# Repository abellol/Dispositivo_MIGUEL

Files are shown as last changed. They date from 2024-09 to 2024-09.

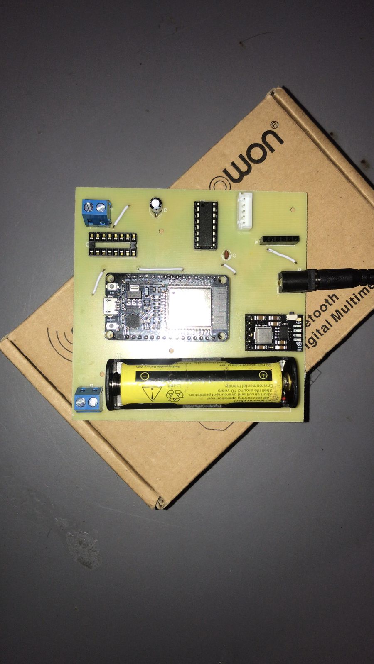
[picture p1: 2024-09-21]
Evidencias/pcb_componentes_2.jpg

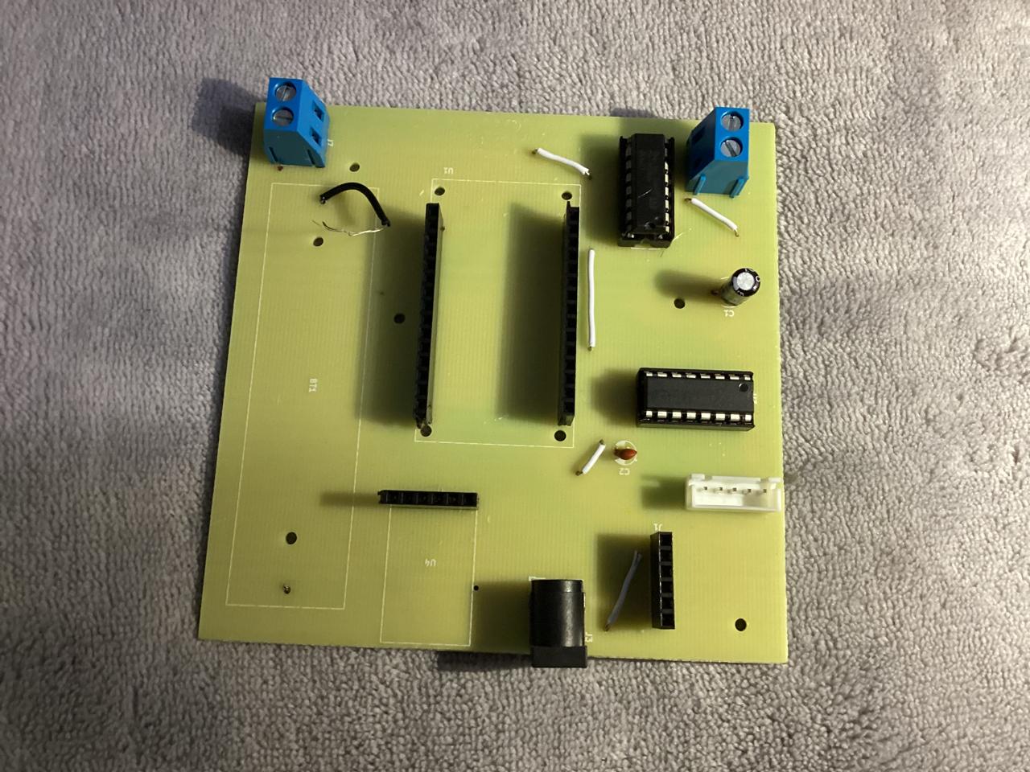
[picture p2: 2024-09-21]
Evidencias/pcb_componentes.jpg

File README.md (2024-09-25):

# Dispositivo_MIGUEL
Desarrollo e implementación de Robot con tecnología LiDAR
### Integrantes
El proyecto fue diseñado y desarrollado por:
| Nombre | Programa |
|:-|:-|
|Alejandro Bello León | ``Ing. Mecatrónica``|
|Ricardo Taizoo Avila Molina | ``Ing. Mecatrónica``|
|Fabio Guillermo Castellanos Lenes | ``Física``|

## Introducción
MIGUEL (Mapeo Inteligente Graficador Utilizando Escaner LiDAR) es un dispositivo autónomo diseñado para navegar por entornos controlados evitando obstaculos y tomando decisiones en tiempo real basadas en los datos que recibe. El vehículo escanea y grafica continuamente su entorno, identificando obstáculos para asegurar un movimiento eficiente dentro del espacio.

El proyecto es una propuesta que abre paso a la exploración a profuncidad de temas relacionados con la robótica, automatización y la integración de sensores.

Puedes visitar nuestra [wiki del proyecto](https://github.com/abellol/Dispositivo_MIGUEL/wiki).

## Póster

(https://postimg.cc/tYdmCQzM)

## Resultado final

https://github.com/user-attachments/assets/6533ad30-b109-4fec-b7e1-59a3a72a6980

## Vídeo explicativo del proyecto

Pueden ver el video en este [enlace](https://www.youtube.com/watch?v=PxDm3hlaaLA) a YouTube

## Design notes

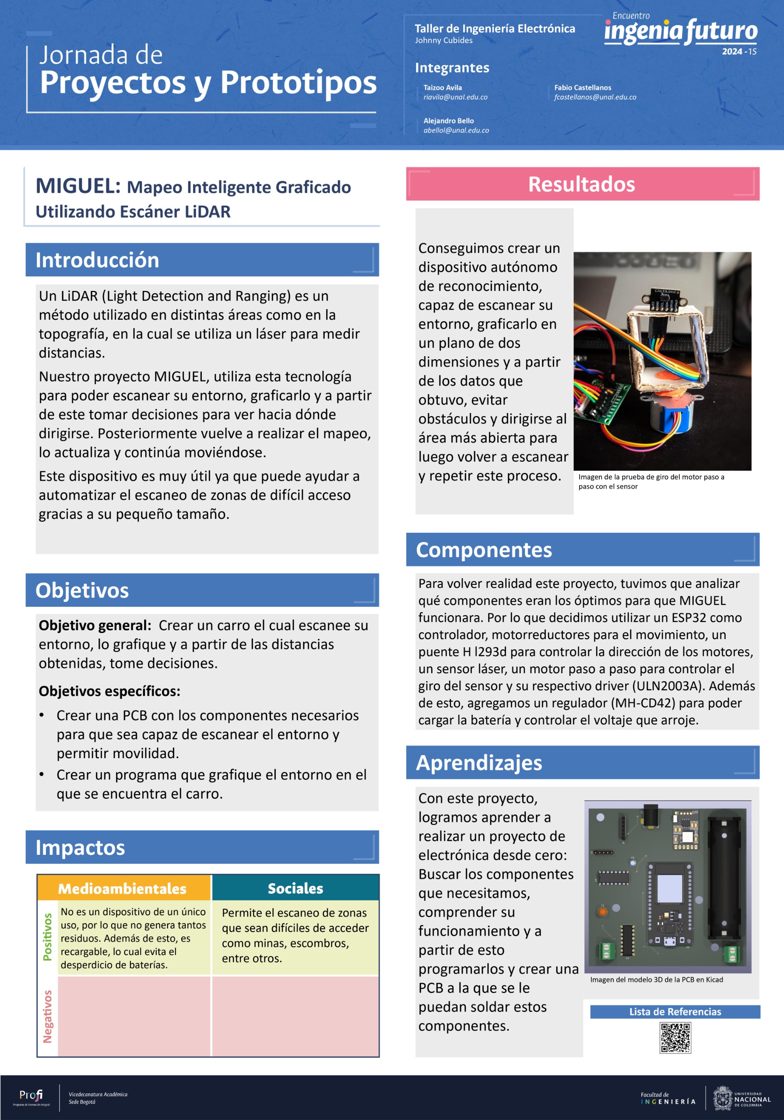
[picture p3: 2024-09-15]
Evidencias/poster_ingenia.jpg

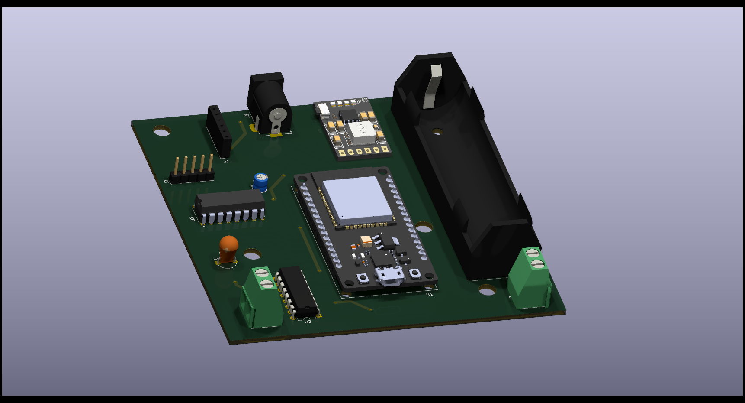
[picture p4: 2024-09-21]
Evidencias/vista_3_MIGUEL.png

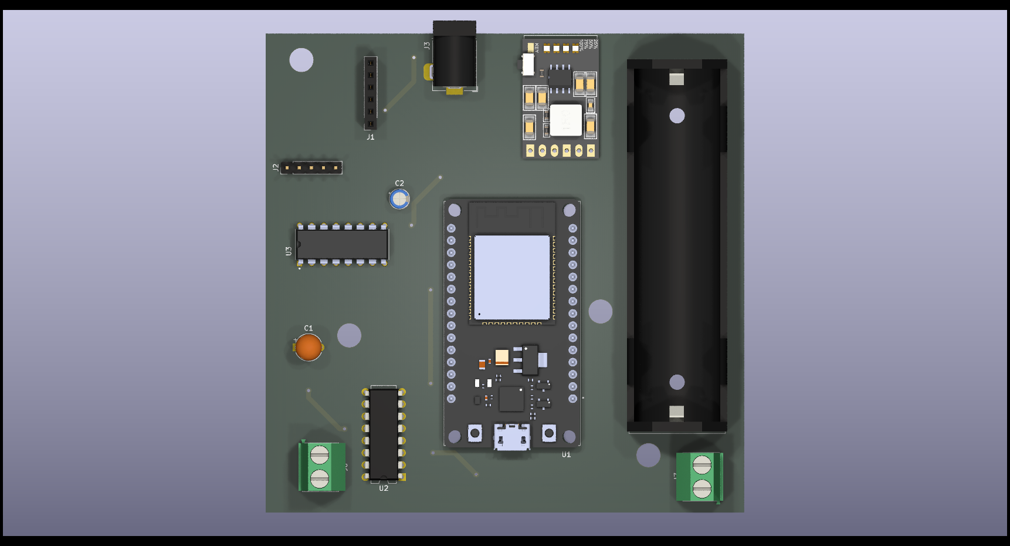
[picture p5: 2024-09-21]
Evidencias/vista_2_MIGUEL.png

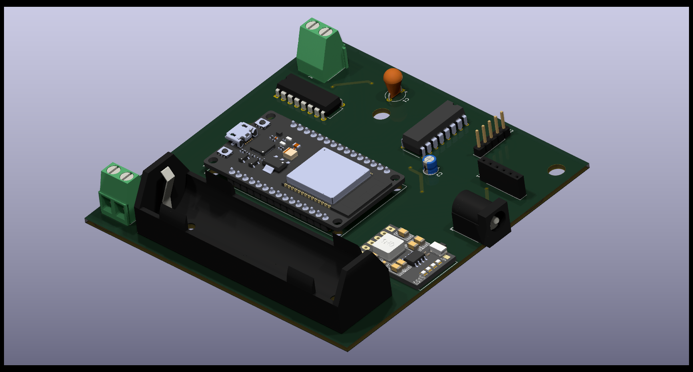
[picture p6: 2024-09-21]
Evidencias/vista_4_MIGUEL.png

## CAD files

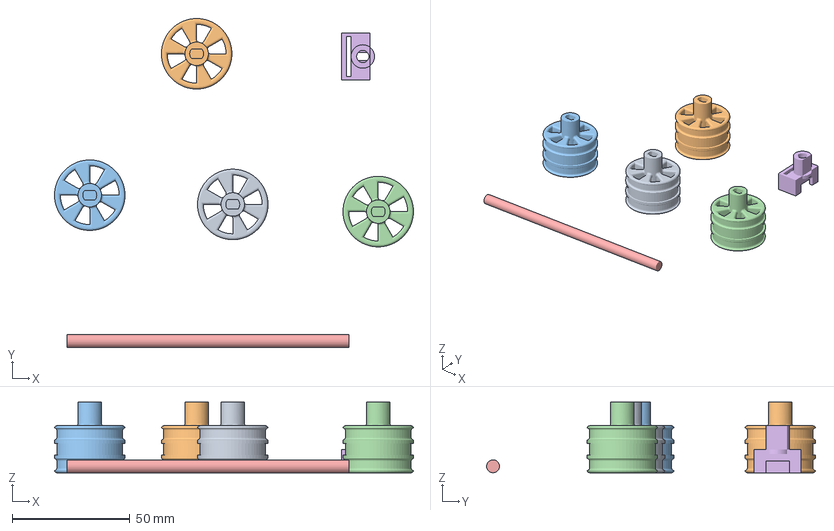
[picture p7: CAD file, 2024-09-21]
Case/piezas_pequeñas.3mf
152.7 x 139.9 x 30.0 mm
Rines.stl x 4
Eje.stl
Soporte sensor.stl

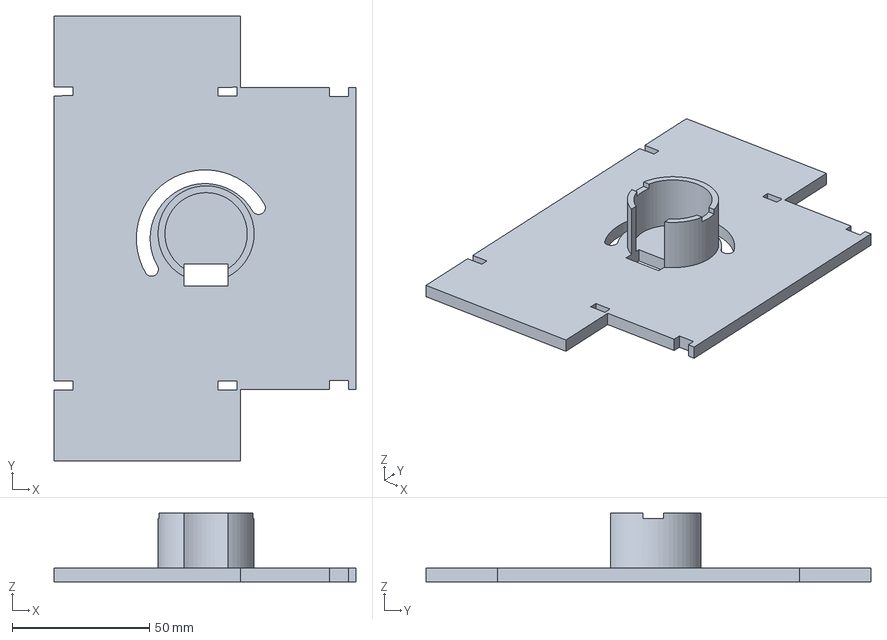
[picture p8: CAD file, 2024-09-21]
Case/tapa_carcasa_real.3mf
110.0 x 162.0 x 25.0 mm

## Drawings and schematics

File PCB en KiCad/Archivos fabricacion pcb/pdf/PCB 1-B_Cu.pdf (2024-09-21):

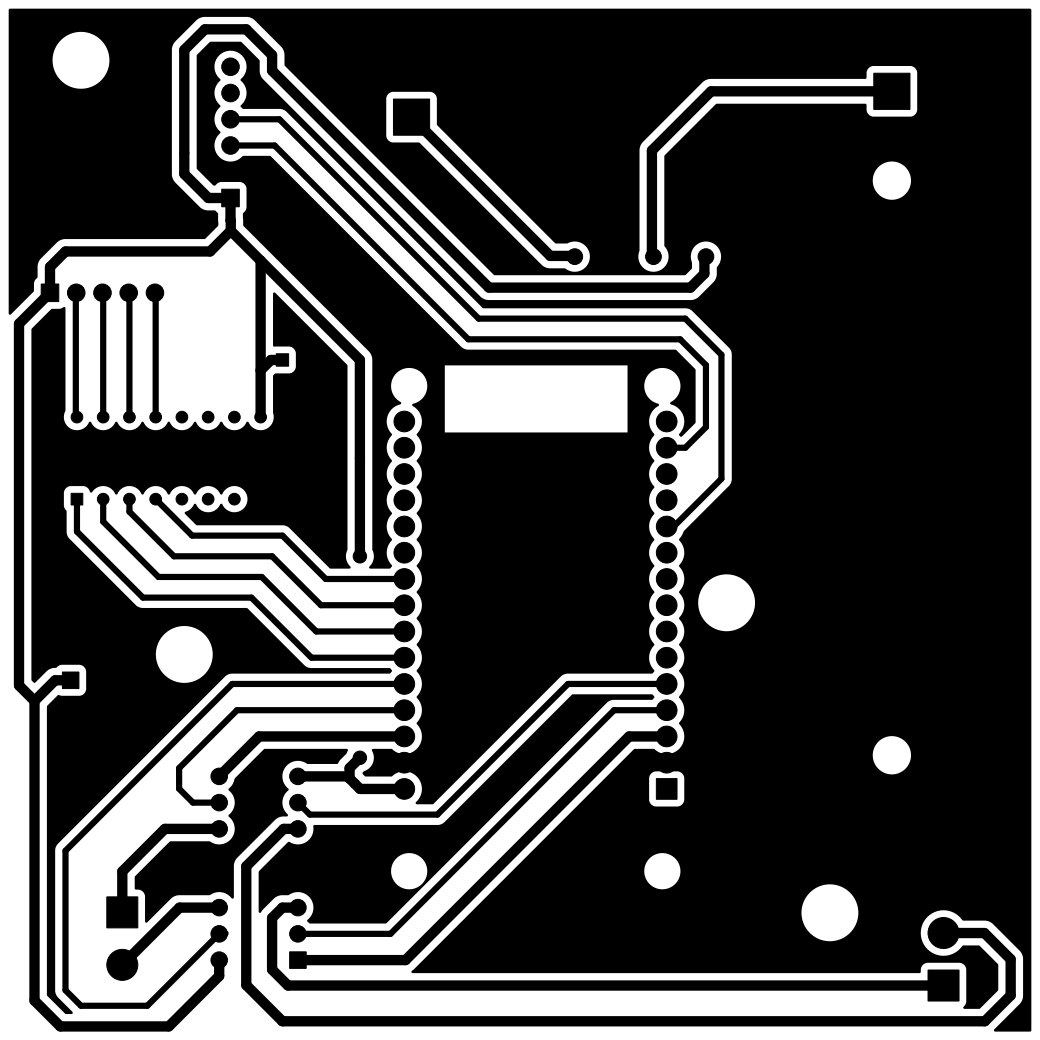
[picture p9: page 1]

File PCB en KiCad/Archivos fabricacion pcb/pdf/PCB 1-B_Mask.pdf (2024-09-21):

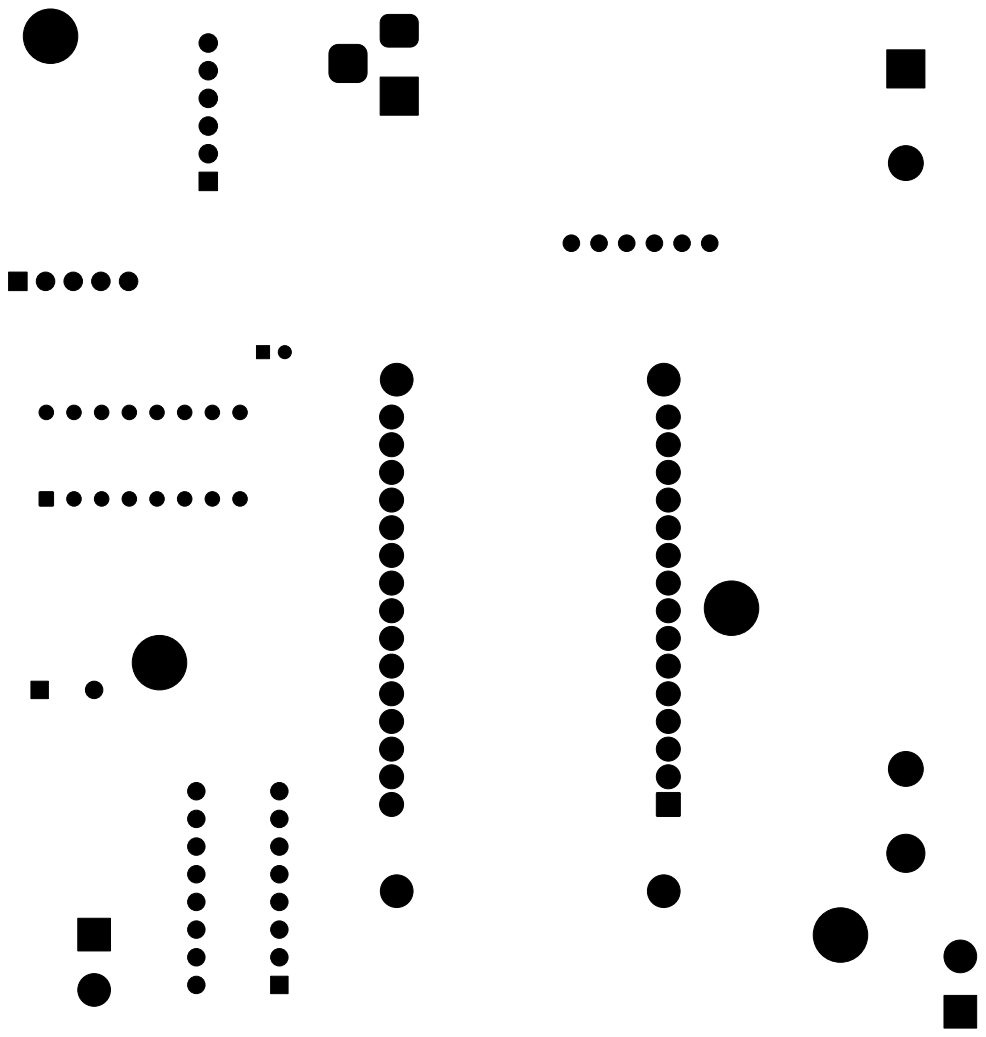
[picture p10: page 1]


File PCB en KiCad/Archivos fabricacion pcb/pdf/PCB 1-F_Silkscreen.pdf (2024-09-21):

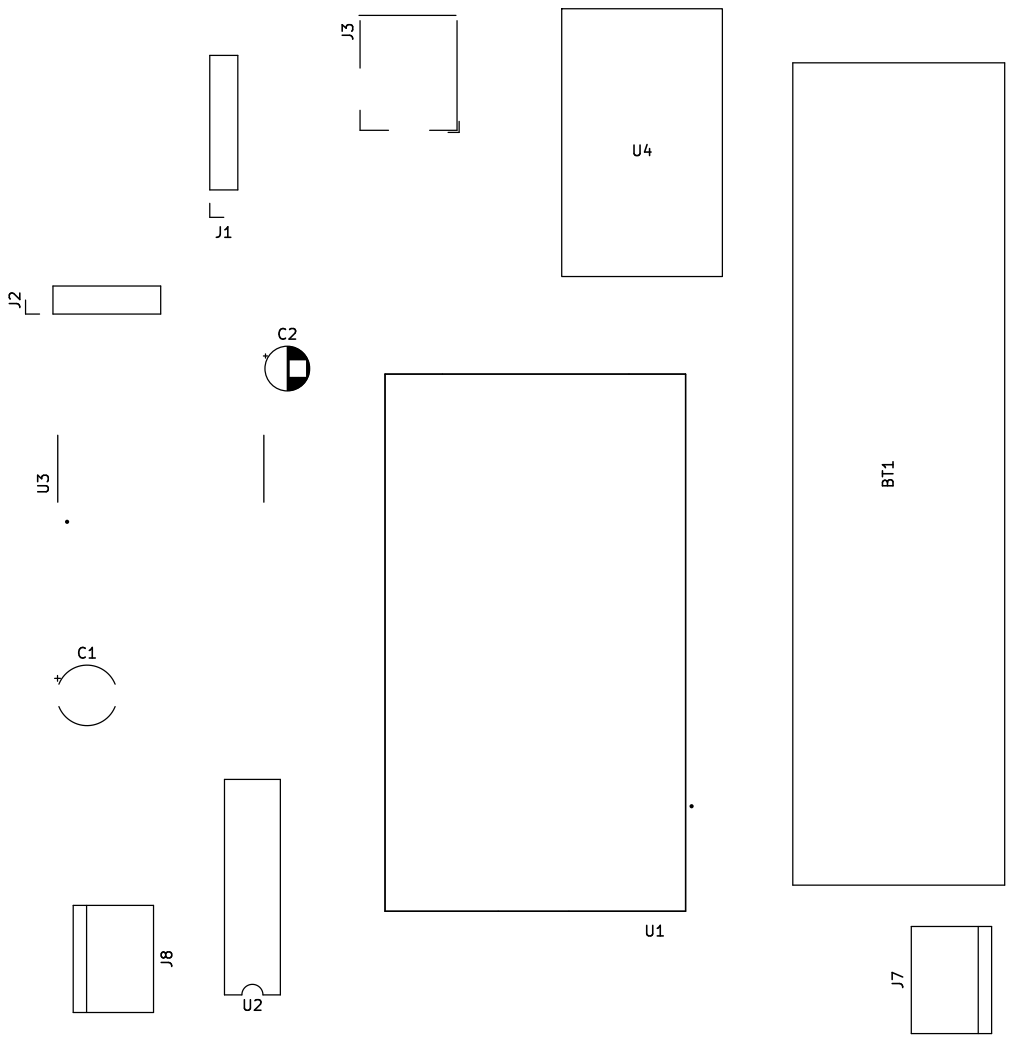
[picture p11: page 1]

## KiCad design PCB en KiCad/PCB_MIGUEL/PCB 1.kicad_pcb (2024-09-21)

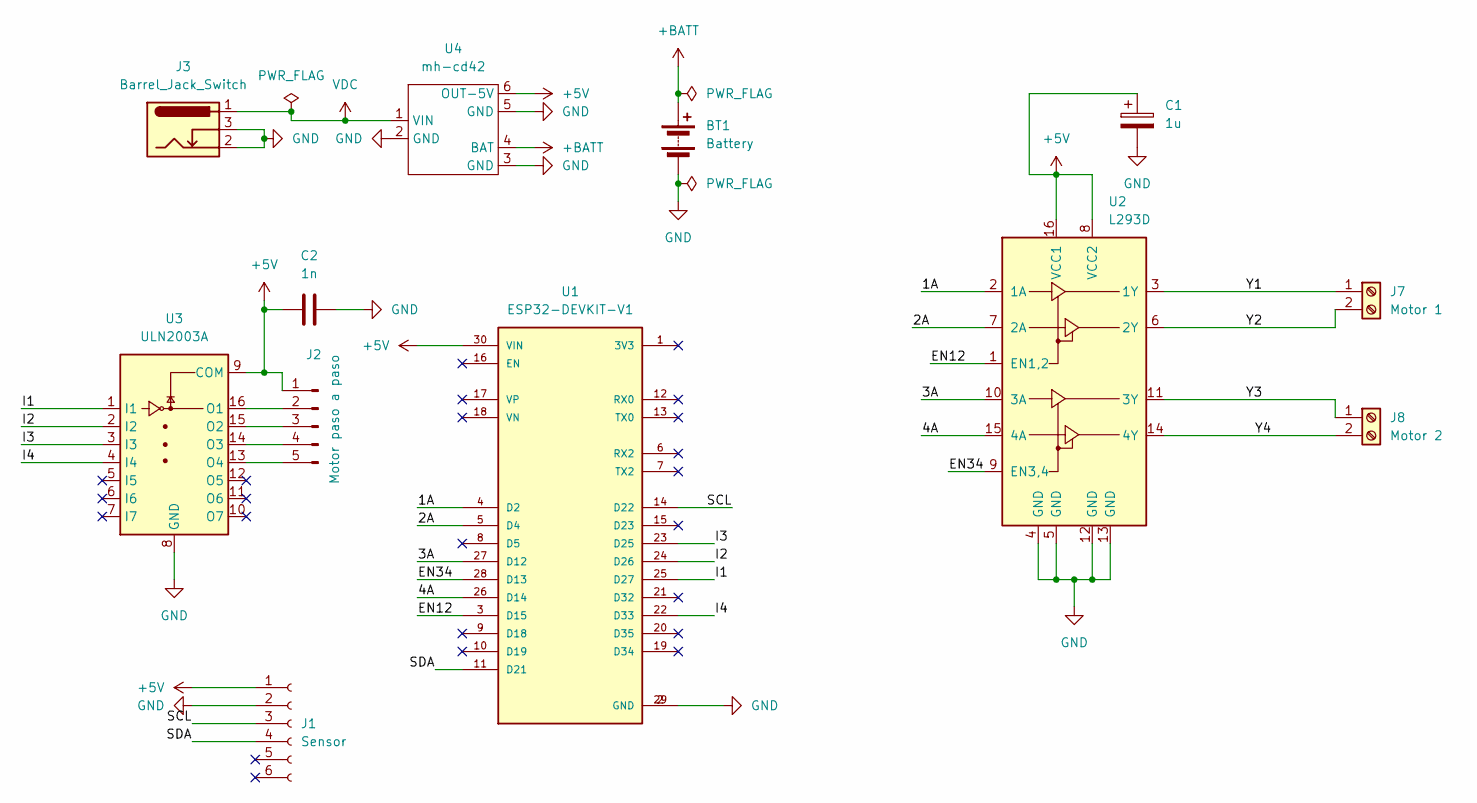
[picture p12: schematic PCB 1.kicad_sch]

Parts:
BT1: Battery; BatteryHolder_MPD_BH-18650-PC2
C1: 1u; CP_Radial_Tantal_D5.5mm_P5.00mm
C2: 1n; CP_Radial_D4.0mm_P2.00mm
J1: Sensor; PinSocket_1x06_P2.54mm_Vertical
J2: Motor paso a paso; PinHeader_1x05_P2.54mm_Vertical
J3: Barrel_Jack_Switch; BarrelJack_Horizontal
J7: Motor 1; TerminalBlock_bornier-2_P5.08mm
J8: Motor 2; TerminalBlock_bornier-2_P5.08mm
U1: ESP32-DEVKIT-V1; MODULE_ESP32_DEVKIT_V1; PARTREV N/A
U2: L293D; DIP-16_W7.62mm
U3: ULN2003A; DIP794W45P254L1969H508Q16
U4: mh-cd42

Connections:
+5V: C1.1, C2.1, J1.1, J2.1, U1.30 (VIN), U2.8 (VCC2), U2.16 (VCC1), U3.9 (COM), U4.6 (OUT-5V)
+BATT: BT1.1 (+), U4.4 (BAT)
/1A: U1.4 (D2), U2.2 (1A)
/2A: U1.5 (D4), U2.7 (2A)
/3A: U1.27 (D12), U2.10 (3A)
/4A: U1.26 (D14), U2.15 (4A)
/EN12: U1.3 (D15), U2.1 (EN1,2)
/EN34: U1.28 (D13), U2.9 (EN3,4)
/I1: U1.25 (D27), U3.1 (I1)
/I2: U1.24 (D26), U3.2 (I2)
/I3: U1.23 (D25), U3.3 (I3)
/I4: U1.22 (D33), U3.4 (I4)
/SCL: J1.3, U1.14 (D22)
/SDA: J1.4, U1.11 (D21)
/Y1: J7.1, U2.3 (1Y)
/Y2: J7.2, U2.6 (2Y)
/Y3: J8.1, U2.11 (3Y)
/Y4: J8.2, U2.14 (4Y)
GND: BT1.2 (-), C1.2, C2.2, J1.2, J3.2, J3.3, U1.2 (GND), U1.29 (GND), U2.4 (GND), U2.5 (GND), U2.12 (GND), U2.13 (GND), U3.8 (GND), U4.2 (GND), U4.3 (GND), U4.5 (GND)
unnamed: J2.2, U3.16 (O1)
unnamed: J2.3, U3.15 (O2)
unnamed: J2.4, U3.14 (O3)
unnamed: J2.5, U3.13 (O4)
VDC: J3.1, U4.1 (VIN)

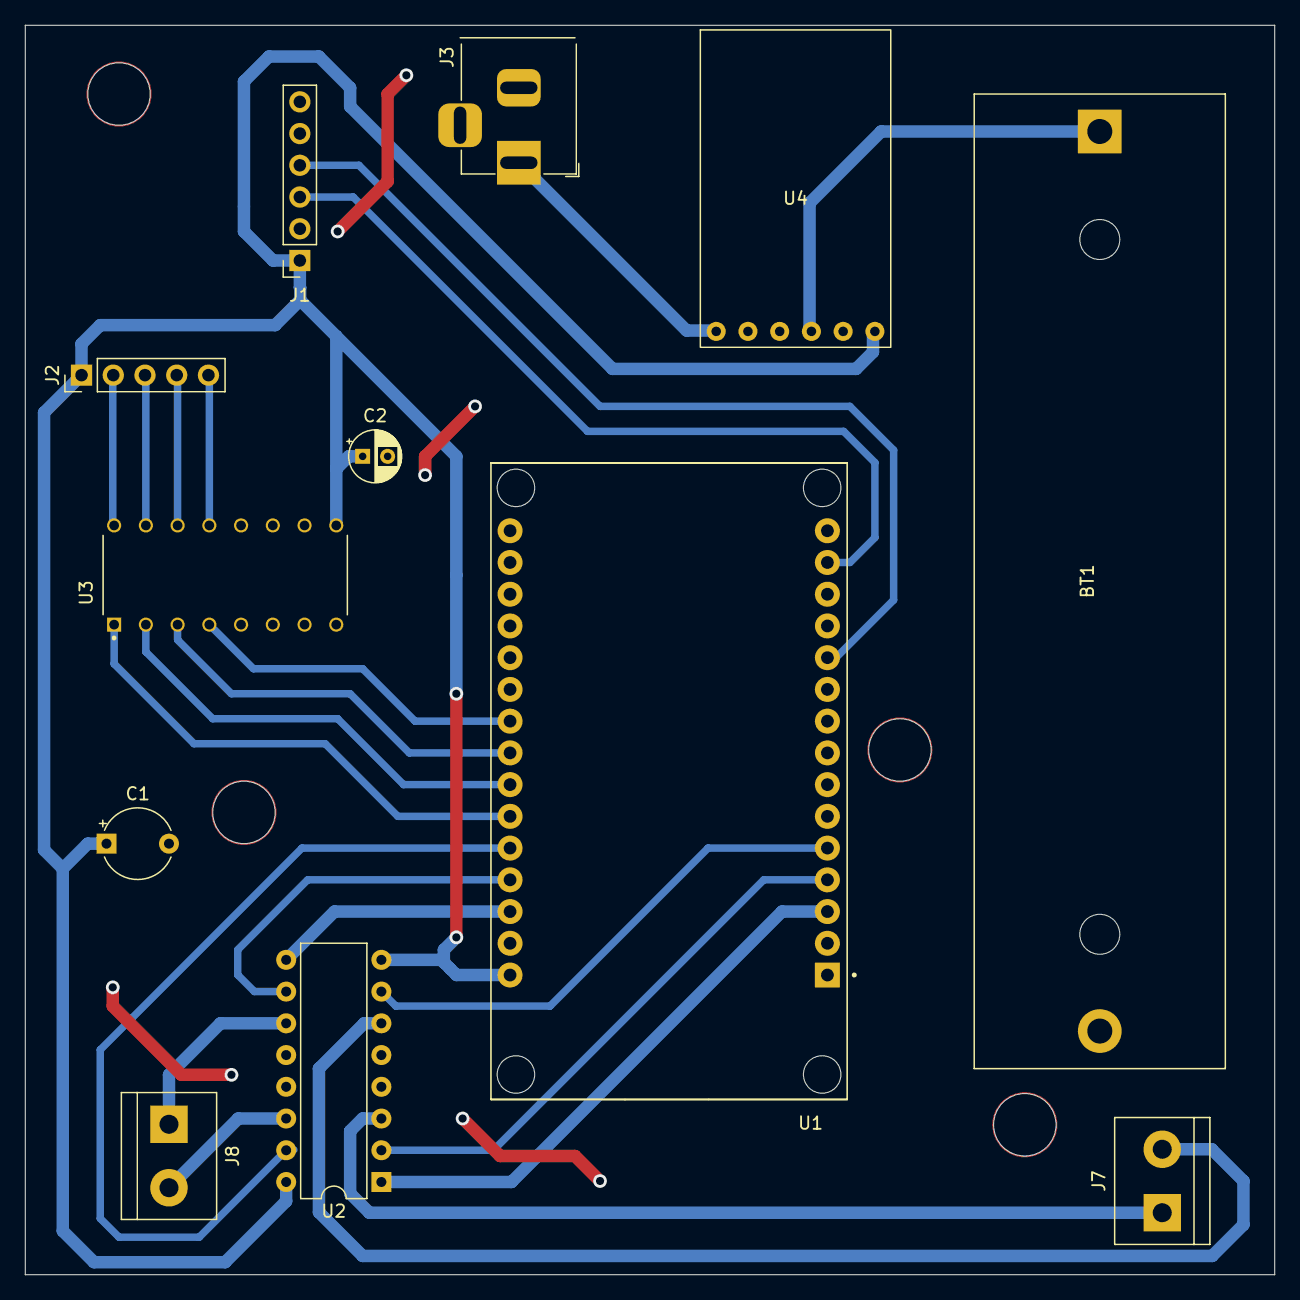
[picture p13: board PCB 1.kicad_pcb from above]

Board: 2 copper layers, 100.0 x 100.0 mm, 12 parts (0 on the bottom side), 24 nets.

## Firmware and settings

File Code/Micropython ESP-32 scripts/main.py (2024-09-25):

import socket
from machine import Pin, I2C
import time
import machine
from VL53L0X import VL53L0X
from wifiAP import connectSTA as connect

# Configuraciones de red
WIFI_SSID = "WIFI RITIN 2"
WIFI_PASSWORD = "Ritis2021"
SERVER_PORT = 3000
BUFFER_SIZE = 128
NUM_LECTURAS = 10

# Declarar los pines de los motorreductores
in1 = Pin(4, Pin.OUT)
in2 = Pin(2, Pin.OUT)
in3 = Pin(14, Pin.OUT)
in4 = Pin(12, Pin.OUT)
d13 = Pin(13, Pin.OUT)
d15 = Pin(15, Pin.OUT)

# Declarar pines del motor paso
IN1 = machine.Pin(27, machine.Pin.OUT)
IN2 = machine.Pin(26, machine.Pin.OUT)
IN3 = machine.Pin(25, machine.Pin.OUT)
IN4 = machine.Pin(33, machine.Pin.OUT)

# Función para controlar la polaridad de los motores frontales
def direction(dire:str):
    d13.value(1)
    d15.value(1)
    if dire == "forward":
        in1.value(1)
        in2.value(0)
        in3.value(1)
        in4.value(0)
    elif dire == "backward":
        in1.value(0)
        in2.value(1)
        in3.value(0)
        in4.value(1)
    elif dire == "left":
        in1.value(0)
        in2.value(1)
        in3.value(1)
        in4.value(0)
    elif dire == "right":
        in1.value(1)
        in2.value(0)
        in3.value(0)
        in4.value(1)
    elif dire == "stop":
        in1.value(0)
        in2.value(0)
        in3.value(0)
        in4.value(0)
# Función para mover el motor, con direccion a favor de las manecillas(1) y en contra(-1)
def motor_half_step(steps, delay, direction = 1):
  half_step = [
    [1, 0, 0, 0],
    [1, 1, 0, 0],
    [0, 1, 0, 0],
    [0, 1, 1, 0],
    [0, 0, 1, 0],
    [0, 0, 1, 1],
    [0, 0, 0, 1],
    [1, 0, 0, 1]
    ]
  if direction == 1:
    for combination in range(steps):
      for step in half_step:
          IN1.value(step[0])
          IN2.value(step[1])
          IN3.value(step[2])
          IN4.value(step[3])
          time.sleep_ms(delay)
  else:
    for combination in range(steps):
      
      for step in range(len(half_step)-1, -1, -1):
          IN1.value(half_step[step][0])
          IN2.value(half_step[step][1])
          IN3.value(half_step[step][2])
          IN4.value(half_step[step][3])
          time.sleep_ms(delay)
          
# Función para conectar el ESP32 a una red WiFi
def conectar_wifi(ssid, password):
    connect(ssid, password)
    print(f"Conectado a la red {ssid}")

# Función para inicializar el sensor VL53L0X
def inicializar_sensor_vl53l0x():
    i2c = I2C(0, scl=Pin(22), sda=Pin(21))
    sensor = VL53L0X(i2c)
    sensor.start()
    return sensor

# Función para crear un socket servidor
def crear_servidor(port):
    server_address = socket.getaddrinfo('0.0.0.0', port)[0][-1]
    sk = socket.socket()
    sk.setsockopt(socket.SOL_SOCKET, socket.SO_REUSEADDR, 1)  # Permitir reutilización del puerto
    sk.bind(server_address)
    sk.listen(1)
    print(f"Servidor escuchando en {server_address}")
    return sk

# Función para leer distancias del sensor y calcular un promedio
def leer_promedio_distancia(sensor, num_lecturas):
    distancia_total = 0
    for _ in range(num_lecturas):
        distancia = sensor.read() + 13  # Suma constante como calibración
        print(f'Distancia: {distancia} mm')
        distancia_total += distancia
        time.sleep(0.1)
    promedio = distancia_total / num_lecturas
    return promedio

# Función principal para manejar conexiones y enviar datos
def manejar_conexion(conn, sensor, num_lecturas, buffer_size):
    try:
        t = 0
        distancias = []
        for i in range(51):
            data = conn.recv(buffer_size)
            if not data:
                break 
            motor_half_step(10,1)
            print(f"Recibido: {data.decode()}")  # Mostrar el dato recibido
            
            # Leer el promedio de distancia y calcular el ángulo
            promedio_distancia = leer_promedio_distancia(sensor, num_lecturas)
            data_value = [promedio_distancia, t]
            t += (360 / 51)
            data_str = str(data_value)
            # Enviar el valor al cliente
            conn.sendall(data_str.encode())
            print(f"Datos enviados: {data_str}")
            distancias.append(promedio_distancia)
        motor_half_step(512, 1, -1)
        distancias = sorted(distancias, reverse=True)
        return (distancias[0])
    finally:
        conn.close()  # Cerrar siempre la conexión al final
        print("Conexion cerrada")


# Función principal para el bucle del servidor
def servidor_tcp(sensor, port, buffer_size, num_lecturas):
    sk = crear_servidor(port)
    try:
        conn, addr = sk.accept()
        print(f"Conexión establecida con {addr}")
        distancias = manejar_conexion(conn, sensor, num_lecturas, buffer_size)
        conn.close()
        print(f"Conexión con {addr} cerrada")
        return distancias
    finally:
        sk.close()  # Asegurarse de que el socket del servidor se cierre siempre
        print("Socket del servidor cerrado")

        
# Función para girar el dispositivo hasta que esté orientado hacia la dirección mas lejana
def tomar_lejana(sensor, umbral_distancia):
    while True:
        direction("right")
        distancia = sensor.read() + 13  # Calibración
        print(f'Distancia actual: {distancia} mm')
        if distancia > (umbral_distancia-(umbral_distancia*0.1)):
            direction("stop")
            break
        time.sleep(0.3)
        
# Función para avanzar hasta que la distancia sea menor o igual a un umbral
def avanzar(sensor, distancia_minima):
    while True:
        direction("forward")
        distancia = sensor.read() + 13
        print(f"La distancia actual es de: {distancia}mm")
        if distancia <= distancia_minima:
            direction("stop")
            break
        time.sleep(0.3)
        
# Programa principal
def main():
    conectar_wifi(WIFI_SSID, WIFI_PASSWORD)
    sensor = inicializar_sensor_vl53l0x()

    while True:  # Ciclo infinito para reiniciar el servidor cada vez que finaliza una conexión
        print("Iniciando servidor...")
        # Ejecutar el servidor TCP y obtener la mayor distancia medida
        distancia_maxima = servidor_tcp(sensor, SERVER_PORT, BUFFER_SIZE, NUM_LECTURAS)
        
        # Girar el dispositivo hacia la dirección de la distancia más lejana
        tomar_lejana(sensor, distancia_maxima)
        avanzar(sensor, 200)

        print("Ciclo completo. Reiniciando servidor...")
        time.sleep(2)

# Ejecutar el programa
if __name__ == "__main__":
    main()

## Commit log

2024-09-16 Archivo para graficar en coordenadas polares
    Versión preliminar, todavía no lee datos de ninguna entrada. Pero es fácilmente configurable debido al dataframe de pandas
2024-09-17 Gráfico en paralelo de datos en tiempo real
    Se crea un hilo diferente para graficar en tiempo real a medida que se van tomando datos
2024-09-21 carga de archivos
    [piezas_pequeñas.3mf, tapa_carcasa_real.3mf]
